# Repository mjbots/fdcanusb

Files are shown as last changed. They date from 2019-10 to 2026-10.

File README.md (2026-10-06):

# mjcanfd-usb-1x / fdcanusb

The mjcanfd-usb-1x and fdcanusb provide access to a CAN-FD bus using a
USB 2.0 full speed connection.  They present two possible interfaces:

1. A `gs_usb` interface compatible with the Linux kernel `gs_usb` socketcan driver
2. serial-like interface over the USB port using the CDC ACM class, i.e. a virtual COM port.

The designs and firmware are licensed under the Apache 2.0 License.

 * 

Pre-assembled hardware can be purchased at https://mjbots.com/products/fdcanusb

## Usage with moteus tools and libraries

To use a device with moteus tools or libraries, first install the
relevant udev rule following the instructions in the top of the file:

* [70-fdcanusb.rules](70-fdcanusb.rules)

Second, just use the application.  moteus utilities like
`moteus_tool`, `tview`, and the python and C++ libraries will
automatically discover any connected devices and use the CDC protocol.

## USB CDC Protocol

Each command or response is a single newline terminated line, composed
of 7-bit ASCII encoded characters.  Every command sent from the client
to the device has a response which consists of an optional command
specific response followed by a final line consisting solely of `OK` or
`ERR <details>`.

### States

The device can be in one of two states.

1. *Bus Off*: This is the initial state of the device.  In this state,
no frames may be sent or received, but the device may be configured.

2. *Bus On*: In this state frames may be sent and received, but
configuration is locked out.

## Commands

Sample commands are prefixed with `>` to show the data sent from the
client to the device and `<` to show the values sent from the device
to the client.  Those characters are for illustrative purposes only,
and are not present in actual communications.

### *conf*

The "conf" command is used to read and set configuration values.  It
has several subcommands.

#### *conf enumerate*

This emits all current configuration values one after another.

#### *conf get*

This queries the value of one specific configuration item.

```
>conf get sample.value
<31235
<OK
```

#### *conf set*

This sets the value of one specific configuration itme.

```
>conf set sample.value 1234
<OK
```

#### *conf load*

This loads all persistent configuration from the persistent storage.

```
>conf load
<OK
```

#### *conf write*

This stores all configuration values to persistent storage.  They will
then be the default when the device is powered on the in the future.

```
>conf write
<OK
```

#### *conf default*

Reset all configuration values to their "default" state.

```
>conf default
<OK
```

### can

#### *can on*

Enter the "Bus On" state.  All configurable values are validated and
put into place.  This results in an error if the device is already in
the "Bus On" state.

#### *can off*

Enter the "Bus Off" state.  Transmission and reception of CAN messages
is halted, and configurable values may be changed.

#### *can std*

Send a standard CAN frame.  The following format is used.

`can std <HEXID> <HEXDATA> <options>`

`options` may be zero or more of the following optionally separated by
spaces.

1. *B/b* require/disable bitrate switching
2. *F/f* require/disable FDCAN format
3. *R/r* require/disable remote frame

#### *can ext*

Send an extended CAN frame.  The following format is used.

`can ext <HEXID> <HEXDATA> <options>`

The allowable options are the same as for `can std`.

#### *can send*

Just like `std` or `ext`, but auto-detect the ID type.

#### *can status*

Report the current mode and status of various flags.

```
>can status
<mode:BUSON
<OK
```

### Receiving CAN Frames

When in the "Bus On" state, the device may spontaneously emit the
following lines upon receipt of valid CAN frames or other errors.

#### *rcv*

A CAN frame has been received.

```
<rcv <HEXID> <HEXDATA> <flags>
```

`flags` may be zero of more of the following separated by spaces:

1. *E/e* frame was received with extended/classic ID
1. *B/b* frame was received with/without bitrate switching
2. *F/f* frame was received in fdcan/classic mode
3. *R/r* frame was remote/data frame
4. tNNNNN timestamp of receipt measured in microseconds
5. fNN integer ID of which filter matched this frame

### Configurable Values

The following items may be configured.

* *can.bitrate* - The bitrate used for the CAN frame (or header only
  if bitrate switching is used.
* *can.fd_bitrate* - The bitrate used for the data and CRC field when
  bitrate switching is used.
* *can.sample_point* - The sample point for the nominal part of the
  CAN frame.  moteus requires 0.666, some other systems default to
  0.75, 0.8, or 0.87.
* *can.fd_sample_sample* - The sample point for the data (BRS) part of
  the CAN frame.  moteus requires 0.666, other systems may require
  alternate settings.
* *can.automatic_retransmission* - When true/non-zero, frames will be
  retried until acknowledged.
* *can.fdcan_frame* - By default, send frames in FDCAN mode
* *can.bitrate_switch* - By default, switch to the `can.fd_bitrate`
  for the data and CRC fields.
* *can.restricted_mode* - Only transmit acknowledgements.
* *can.bus_monitor* - Transmit nothing.
* *can.termination* - Enable the onboard terminator
* *can.autostart* - Enter BusOn immediately at power-on
* *can.autorecover* - Automatically recover from bus off events

* *can.global.std_action*
* *can.global.ext_action*
* *can.global.remote_std_action*
* *can.global.remote_ext_action*
  * 0/1 - accept
  * 2 - reject

* *can.filter.N.id1* - first ID
* *can.filter.N.id2* - second ID or bitmask
* *can.filter.N.mode*
  * 0 - range
  * 1 - exact match
  * 2 - bitmask
* *can.filter.N.type*
  * 0 - standard
  * 1 - extended
* *can.filter.N.action*
  * 0 - disable
  * 1 - accept
  * 2 - reject

## gs_usb interface

To use the device with a socketcan driver on Linux, the normal socketcan utilities can be used.  For instance, to bring up an interface compatible with moteus (not usually required because moteus tools and libraries will by default use the CDC interface), you would do:

```bash
ip link set can0 up type can \
  bitrate 1000000 dbitrate 5000000 \
  sjw 10 dsjw 5 \
  sample-point 0.666 dsample-point 0.666 \
  fd on
```

Then, all messages received can be displayed with:

```bash
candump can0
```

## Building firmware

To build the firmware on an Ubuntu 22.04 or newer system.

```
sudo apt install curl openocd
./tools/bazel build //...
```

To flash:

```
./flash.py
```

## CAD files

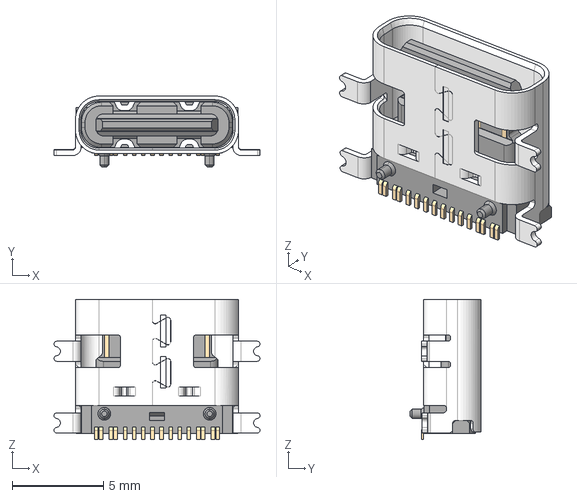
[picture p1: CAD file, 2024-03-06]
hw/3d/usb4110-gf-a.stp
11.3 x 3.89 x 7.70 mm

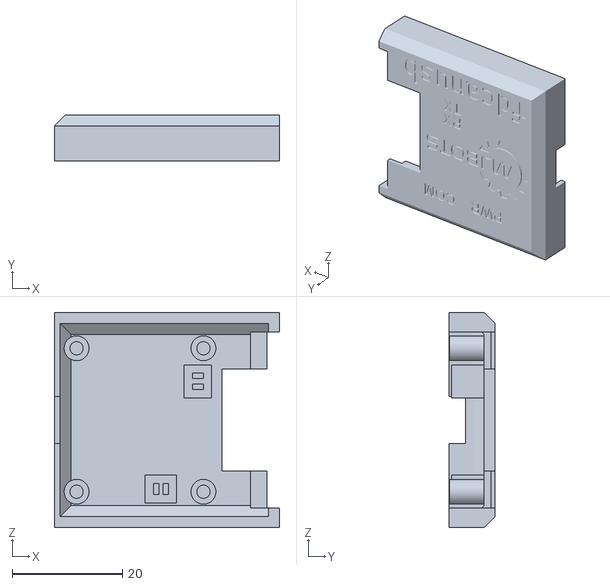
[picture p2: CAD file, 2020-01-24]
hw/enclosure/fdcanusb_20200122/fdcanusb_enclosure_top.stl
40.8 x 8.40 x 39.0

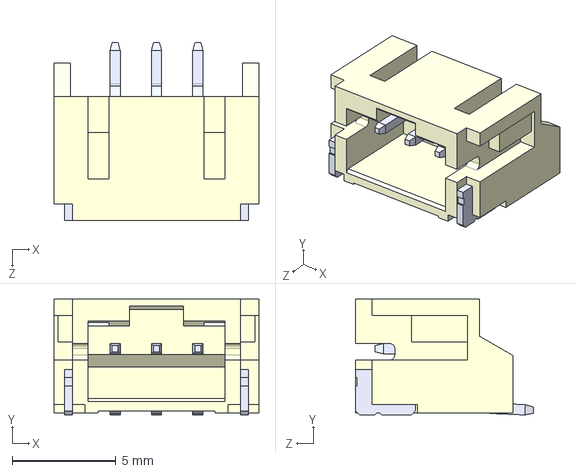
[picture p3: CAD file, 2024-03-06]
hw/3d/S3B-PH-SM4-TB_LF__SN_.step
9.90 x 5.60 x 8.60 mm

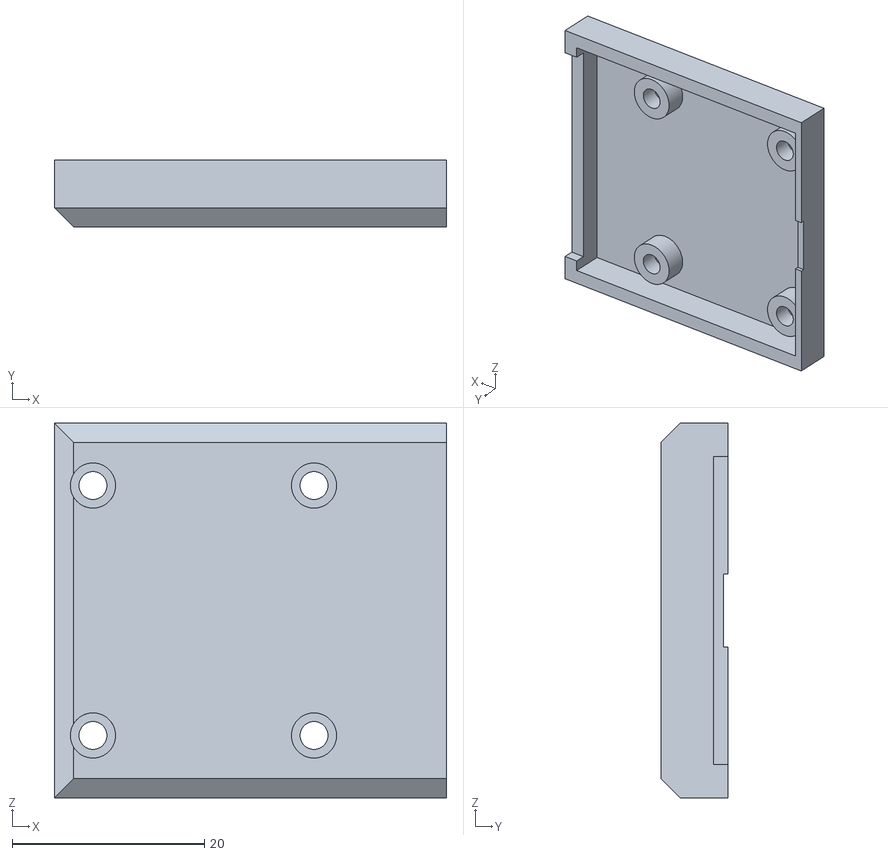
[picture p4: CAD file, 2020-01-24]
hw/enclosure/fdcanusb_20200122/fdcanusb_enclosure_bottom.stl
40.8 x 7.00 x 39.0

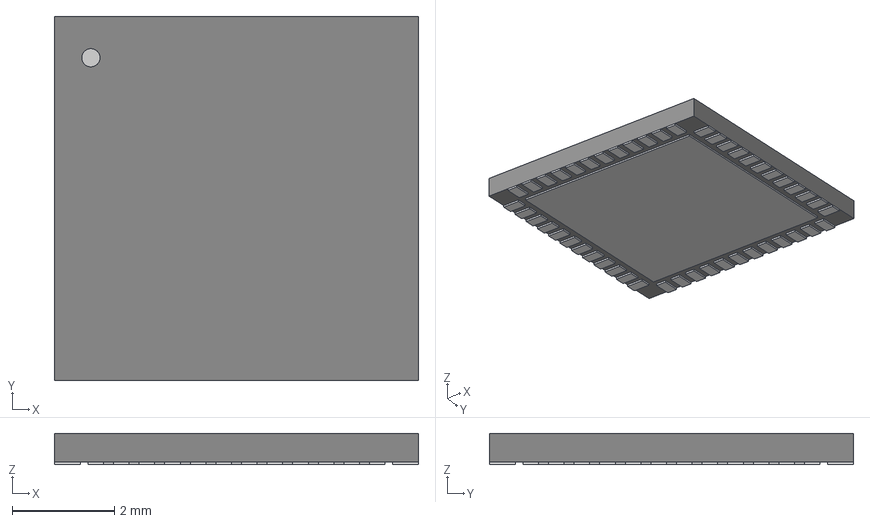
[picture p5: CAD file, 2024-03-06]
hw/3d/UFQFPN-48_7X7X0P55MM.step
7.11 x 7.11 x 0.612 mm

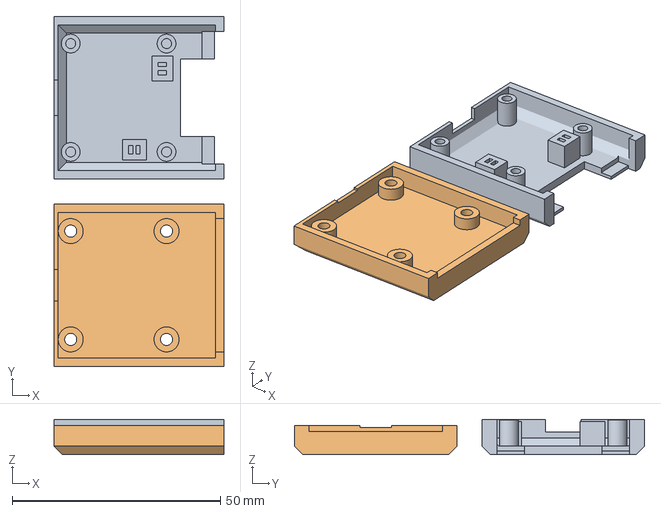
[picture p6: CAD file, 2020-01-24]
hw/enclosure/fdcanusb_20200122/fdcanusb_enclosure.3mf
40.8 x 84.0 x 8.40 mm
fdcanusb_enclosure_top.stl
fdcanusb_enclosure_bottom.stl

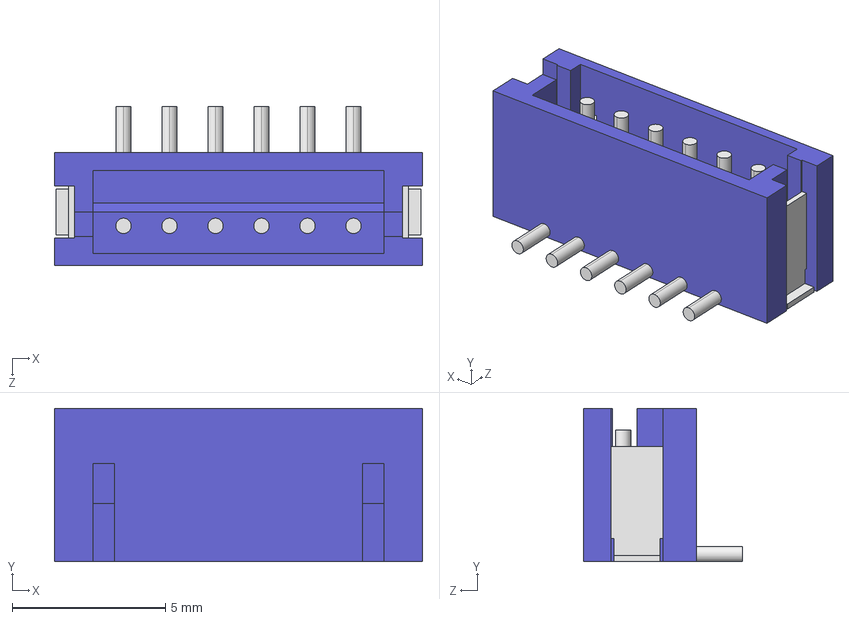
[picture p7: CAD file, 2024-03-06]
hw/3d/B6B-ZR-SM4-TF.STEP
12.0 x 5.00 x 5.20 mm

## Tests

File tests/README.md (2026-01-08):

# fdcanusb Hardware-in-the-Loop Test Suite

Some tests can be performed using a physical test fixture.

## Hardware Overview

The test fixture consists of:

* A Legacy CDC-based fdcanusb: serial B79E5874
* The Device Under Test (DUT): serial 79678ECE
* A debug UART: /dev/serial/by-id/usb-FTDI_UMFT230XB_FT6VJM97-if00-port0`

The two fdcanusb devices are connected onto a common CAN bus, and the
debug UART is connected to the TX LED of the DUT under test.

## Prerequisites

```bash
sudo apt install can-utils
```

## Usage

Several commands either need to be configured for passwordless `sudo`,
or the tests must be run as root.

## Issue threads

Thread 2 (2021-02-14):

CAN Socket support?

vibnwis, 2021-02-14:
Does it support CAN Socket?

jpieper, 2021-02-14:
The daemon found here https://github.com/mjbots/fdcanusb/blob/master/sw/fdcanusb_daemon.cc can be used to provide a socketcan interface from the fdcanusb.

vibnwis, 2021-02-14:
Many thanks for the response. However, having searched high and low, yet not seeing the hardware for your code.  What or where is the hardware?

jpieper, 2021-02-14:
https://github.com/mjbots/fdcanusb/tree/master/hw

jpieper, 2021-02-14:
When they are in stock, you can also buy them at https://mjbots.com/products/fdcanusb

vibnwis, 2021-02-14:
The description of "serial-like" is confusing, despite me a embedded
engineer and familiar with CAN-bus not so sure it is a CAN-bus device or
Serial-like CAN-bus, please elaborate?

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

jpieper, 2021-02-14:
When inserted into a USB port, it implements the USB CDC interface.  That means it looks like a virtual COM port to Window or Linux.

When you use a terminal emulator like hyperterminal or minicom, it allows you to send commands which cause CAN-FD frames to be emitted out the other side.  CAN-FD frames that are successfully received, are reported as responses on that same USB CDC interface.

vibnwis, 2021-02-14:
Thank you for the explanation. I need a USB-FDCAN adapter. Your product
does not suit my needs. Thank you

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

jpieper, 2021-02-14:
No worries.  Although, a USB CAN-FD adapter is exactly what this is.  I'm not sure what else you would expect from such an adapter.

vibnwis, 2021-02-14:
Simply, USB<->CANFD, so that I can have an FDCAN device on my PC through
USB.

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

jpieper, 2021-02-14:
That is exactly what this device lets you do.

Every USB to CAN-FD adapter has a unique protocol on the PC side.  The fdcanusb's is documented in the README, and additionally there is the daemon linked above that lets it present as a linux socketcan device.

vibnwis, 2021-02-14:
I re-visited your explanation, and realize that the serial-like is an emulation. Without emulation, it is a USB-FDCAN device. I need a device for my research studies. Hence, do not have much time for trouble-shooting. Is the product as CAN Socket promising or working. I can compile the Linux driver, but just wanting to know it is not stable, not a beta release, is it?

jpieper, 2021-02-14:
It is plenty stable for mjbots' needs.  However, you may decide you'd rather get something like the PEAK USB CAN-FD adapter, which while significantly more expensive, is provided by a company with a longer history.

https://www.peak-system.com/PCAN-USB-FD.365.0.html?&L=1

vibnwis, 2021-02-14:
However, the website says it is out of stock and sold out?

jpieper, 2021-02-14:
Yes, as the website says, the ETA of new stock is approximately 1 week.

vibnwis, 2021-02-14:
How does it take an order?

jpieper, 2021-02-14:
If you are asking how to place an order at mjbots.com, you can wait until it is in stock, then pay with a credit card or google pay using the automated online checkout.

vibnwis, 2021-02-14:
Got it! I was thinking if I can place an order now, and pay when it is in
stock. All good. Thanks

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

jpieper, 2021-02-14:
Great!  I'll close this issue out for now then.  If you have more questions, don't hesitate to mail info@mjbots.com or joint the mjbots discord: https://discord.gg/W4hUpBb

vibnwis, 2021-02-25:
Hi there,
The FDCAN USB adapter is available now. However, it does not ship to New Zealand. Can you help, please?

jpieper, 2021-02-25:
Shipping to New Zealand should work.  Can you mail info@mjbots.com with a screenshot of any errors you are seeing?

vibnwis, 2021-02-25:
Sent

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

Closed 2021-02-14.

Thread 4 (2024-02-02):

Configuration is not saved well

remixoff, 2024-02-02:
```
conf set can.restricted_mode  0
OK
conf write
OK
conf get can.restricted_mode
ERR error reading
```

jpieper, 2024-02-02:
Likely you used backspace or other non-printable characters.  While human readable, the protocol isn't necessarily human friendly.

```
conf enumerate
```

Will also display all configuration.  Can you try again, perhaps pasting to avoid having to backspace?

jpieper, 2024-04-12:
Closing this as there as been no response.

Closed 2024-04-12.

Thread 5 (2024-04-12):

build error

AoyunTech, 2024-04-12:
Hi Josh,
 Would you know how to fix this build errs?

Thanks

~/github/mjbots/fdcanusb$ ./tools/bazel build //fw:fdcanusb.bin
Downloading bazel 5.4.1 from https://github.com/bazelbuild/bazel/releases/download/5.4.1/bazel-5.4.1-linux-x86_64
  % Total    % Received % Xferd  Average Speed   Time    Time     Time  Current
                                 Dload  Upload   Total   Spent    Left  Speed
  0     0    0     0    0     0      0      0 --:--:--  0:00:32 --:--:--     0
100 49.4M  100 49.4M    0     0  45333      0  0:19:03  0:19:03 --:--:-- 1738k
Traceback (most recent call last):
  File "./tools/bazel", line 108, in <module>
    main()
  File "./tools/bazel", line 101, in main
    download_bazel(bazel_bin_loc)
  File "./tools/bazel", line 88, in download_bazel
    raise RuntimeError(
RuntimeError: bazel sha256 does not match, expected e3b0c44298fc1c149afbf4c8996fb92427ae41e4649b934ca495991b7852b855 got 5d90515f84b5ee1fd6ec22ee9e83103e77ed1a907ee5eec198fef3a5b45abf13

jpieper, 2024-04-12:
You likely have a proxy or something that is modifying the contents of the file that it is downloading: https://github.com/bazelbuild/bazel/releases/download/5.4.1/bazel-5.4.1-linux-x86_64

I just downloaded it here again and got the expected hash of 5d90515f84b5ee1fd6ec22ee9e83103e77ed1a907ee5eec198fef3a5b45abf13 which is what is present in https://github.com/mjbots/fdcanusb/blob/7b0a188b39cb8ea94958e9601762a55b619bf2a0/WORKSPACE#L20

AoyunTech, 2024-04-13:
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

Hi Josh,
It's my mistakes.

Thanks for your reply!
Thanks

But i missed another issue when retry building again.
LOG as
1:~/github/mjbots/fdcanusb$ ./tools/bazel build //fw:fdcanusb.bin
Traceback (most recent call last):
  File "./tools/bazel", line 107, in <module>
    main()
  File "./tools/bazel", line 102, in main
    os.execv(bazel_bin_loc, ['bazel', ] + sys.argv[1:])
OSError: [Errno 8] Exec format error

Hope your suggestions please.

jpieper, 2024-04-13:
The build process is only supported on a x64 Linux system.  I'm guessing you have a different architecture or OS.

Closed 2024-10-16.

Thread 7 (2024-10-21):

Could not detect fdcanusb

bybayin, 2024-10-21:
Hello, I have a problem and I was wondering if you could help me. When I was trying to connect to the FDCANUSB, I got an unexpected message in the console that says "Could not detect FDCANUSB." How can I resolve this issue?
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

jpieper, 2024-10-21:
Do you have a fdcanusb connected to your computer?  Is the red PWR light illuminated on the fdcanusb?

bybayin, 2024-10-21:
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

This is the source code I compiled for fdcanUSB and burned it onto my custom PCB board. The burning program was successful, but the PWR light did not turn on after powering on. The computer USB recognized this device as DFU in FS Mode

jpieper, 2024-10-21:
mjbots does not provide support for custom built boards.  If you have further issues, you should ask in the mjbots Discord in the #ibuiltit channel: https://discord.gg/W4hUpBb

That said, it sounds like you have not set the option bytes.  There is a script in the moteus repo: https://github.com/mjbots/moteus/blob/main/fw/program_option_bytes.sh

Closed 2024-10-21.

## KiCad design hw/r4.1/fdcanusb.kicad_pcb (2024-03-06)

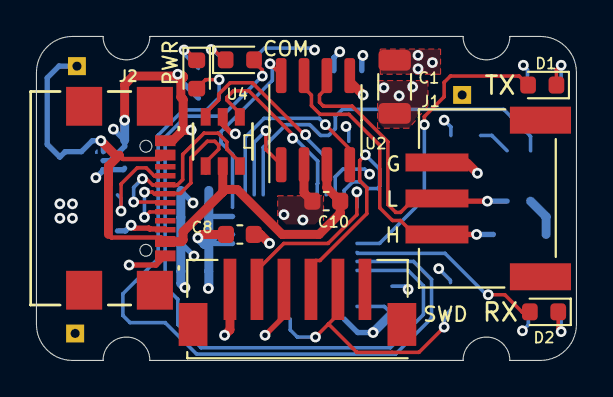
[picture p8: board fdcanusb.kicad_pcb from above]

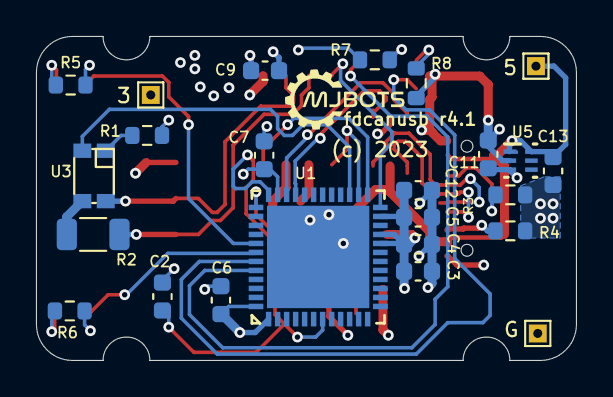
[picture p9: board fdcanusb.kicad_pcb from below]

Board: 4 copper layers, 30.0 x 18.0 mm, 36 parts (24 on the bottom side), 28 nets.

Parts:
C1: 10uF; C_1206_3216Metric
C2, C4, C6, C7, C8, C9, C10, C12: 0.1uF; C_0603_1608Metric
C3: 4.7uF; C_0603_1608Metric
C5, C11, C13: 1uF; C_0603_1608Metric
D1, D3: GREEN; LED_0603_1608Metric
D2, D4: RED; LED_0603_1608Metric
J1: Conn_01x03; JST_S3B-PH-SM4-TB(LF)(SN)
J2: USB4110-GF-A; USB4110-GF-A_GCT
J3, J4, J5: Conn_01x01; TestPoint_THTPad_1.0x1.0mm_Drill0.5mm
R1: 330; R_0603_1608Metric
R2: 110; R_1206_3216Metric
R3, R4: 5.1k; R_0603_1608Metric
R5, R6, R7, R8: 220; R_0603_1608Metric
SWD1: B6B-ZR-SM4-TF(LF)(SN); B6B-ZR-SM4-TFLFSN
U1: STM32G474CEU6; UFQFPN-48_7X7X0P55MM
U2: TCAN1057AEVDRQ1; SOIC-8_3.9x4.9mm_P1.27mm
U3: TLP3317
U4: USBLC6-2SC6; SOT23-6L_STM
U5: TLV70233DSER; DSE0006A

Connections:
+3V: C1.1, C3.1, C4.1, C5.1, C6.1, C7.1, C8.1, C9.1, C11.1, C12.1, J4.1, R1.1, SWD1.6, U1.1 (VBAT), U1.20 (VREF+), U1.21 (VDDA), U1.23 (VDD), U1.35 (VDD), U1.48 (VDD), U2.5 (VIO), U5.3 (OUT)
+5V: C10.1, C13.1, J2.A4-B9 (VBUS), J2.A9-B4 (VBUS), J5.1, U2.3 (VCC), U4.5, U5.1 (IN), U5.6 (EN)
/CAN/CAN_N: J1.2, U2.6 (CANL), U3.4
/CAN/CAN_P: J1.1, R2.2, U2.7 (CANH)
/CAN/CAN_RX: U1.25 (PB12), U2.4 (RXD)
/CAN/CAN_STB: U1.24 (PB11), U2.8 (STB)
/CAN/CAN_TERM: U1.27 (PB14), U3.2
/CAN/CAN_TX: U1.26 (PB13), U2.1 (TXD)
/LED Debug/LED_CAN_RX: D2.2 (A), U1.42 (PB4)
/LED Debug/LED_CAN_TX: D1.2 (A), U1.41 (PB3)
/LED Debug/LED_COM: D3.2 (A), U1.44 (PB6)
/LED Debug/LED_PWR: D4.2 (A), U1.43 (PB5)
/Power Input/USB_F_N: U1.33 (PA11), U4.1
/Power Input/USB_F_P: U1.34 (PA12), U4.3
/Power Input/USB_N: J2.A7 (DN1), J2.B7 (DN2), U4.6
/Power Input/USB_P: J2.A6 (DP1), J2.B6 (DP2), U4.4
/stm32g4/NRST: C2.1, SWD1.2, U1.7 (PG10-NRST)
/stm32g4/SWCLK: SWD1.5, U1.37 (PA14)
/stm32g4/SWDIO: SWD1.3, U1.36 (PA13)
GND: C1.2, C2.2, C3.2, C4.2, C5.2, C6.2, C7.2, C8.2, C9.2, C10.2, C11.2, C12.2, C13.2, J1.3, J2.A1-B12 (GND), J2.A12-B1 (GND), J3.1, R3.2, R4.2, R5.2, R6.2, R7.2, R8.2, SWD1.4, U1.49 (EPAD), U2.2 (GND), U4.2, U5.2 (GND)
unnamed: D1.1 (K), R5.1
unnamed: D2.1 (K), R6.1
unnamed: D3.1 (K), R7.1
unnamed: D4.1 (K), R8.1
unnamed: J2.A5 (CC1), R3.1
unnamed: J2.B5 (CC2), R4.1
unnamed: R1.2, U3.1
unnamed: R2.1, U3.3

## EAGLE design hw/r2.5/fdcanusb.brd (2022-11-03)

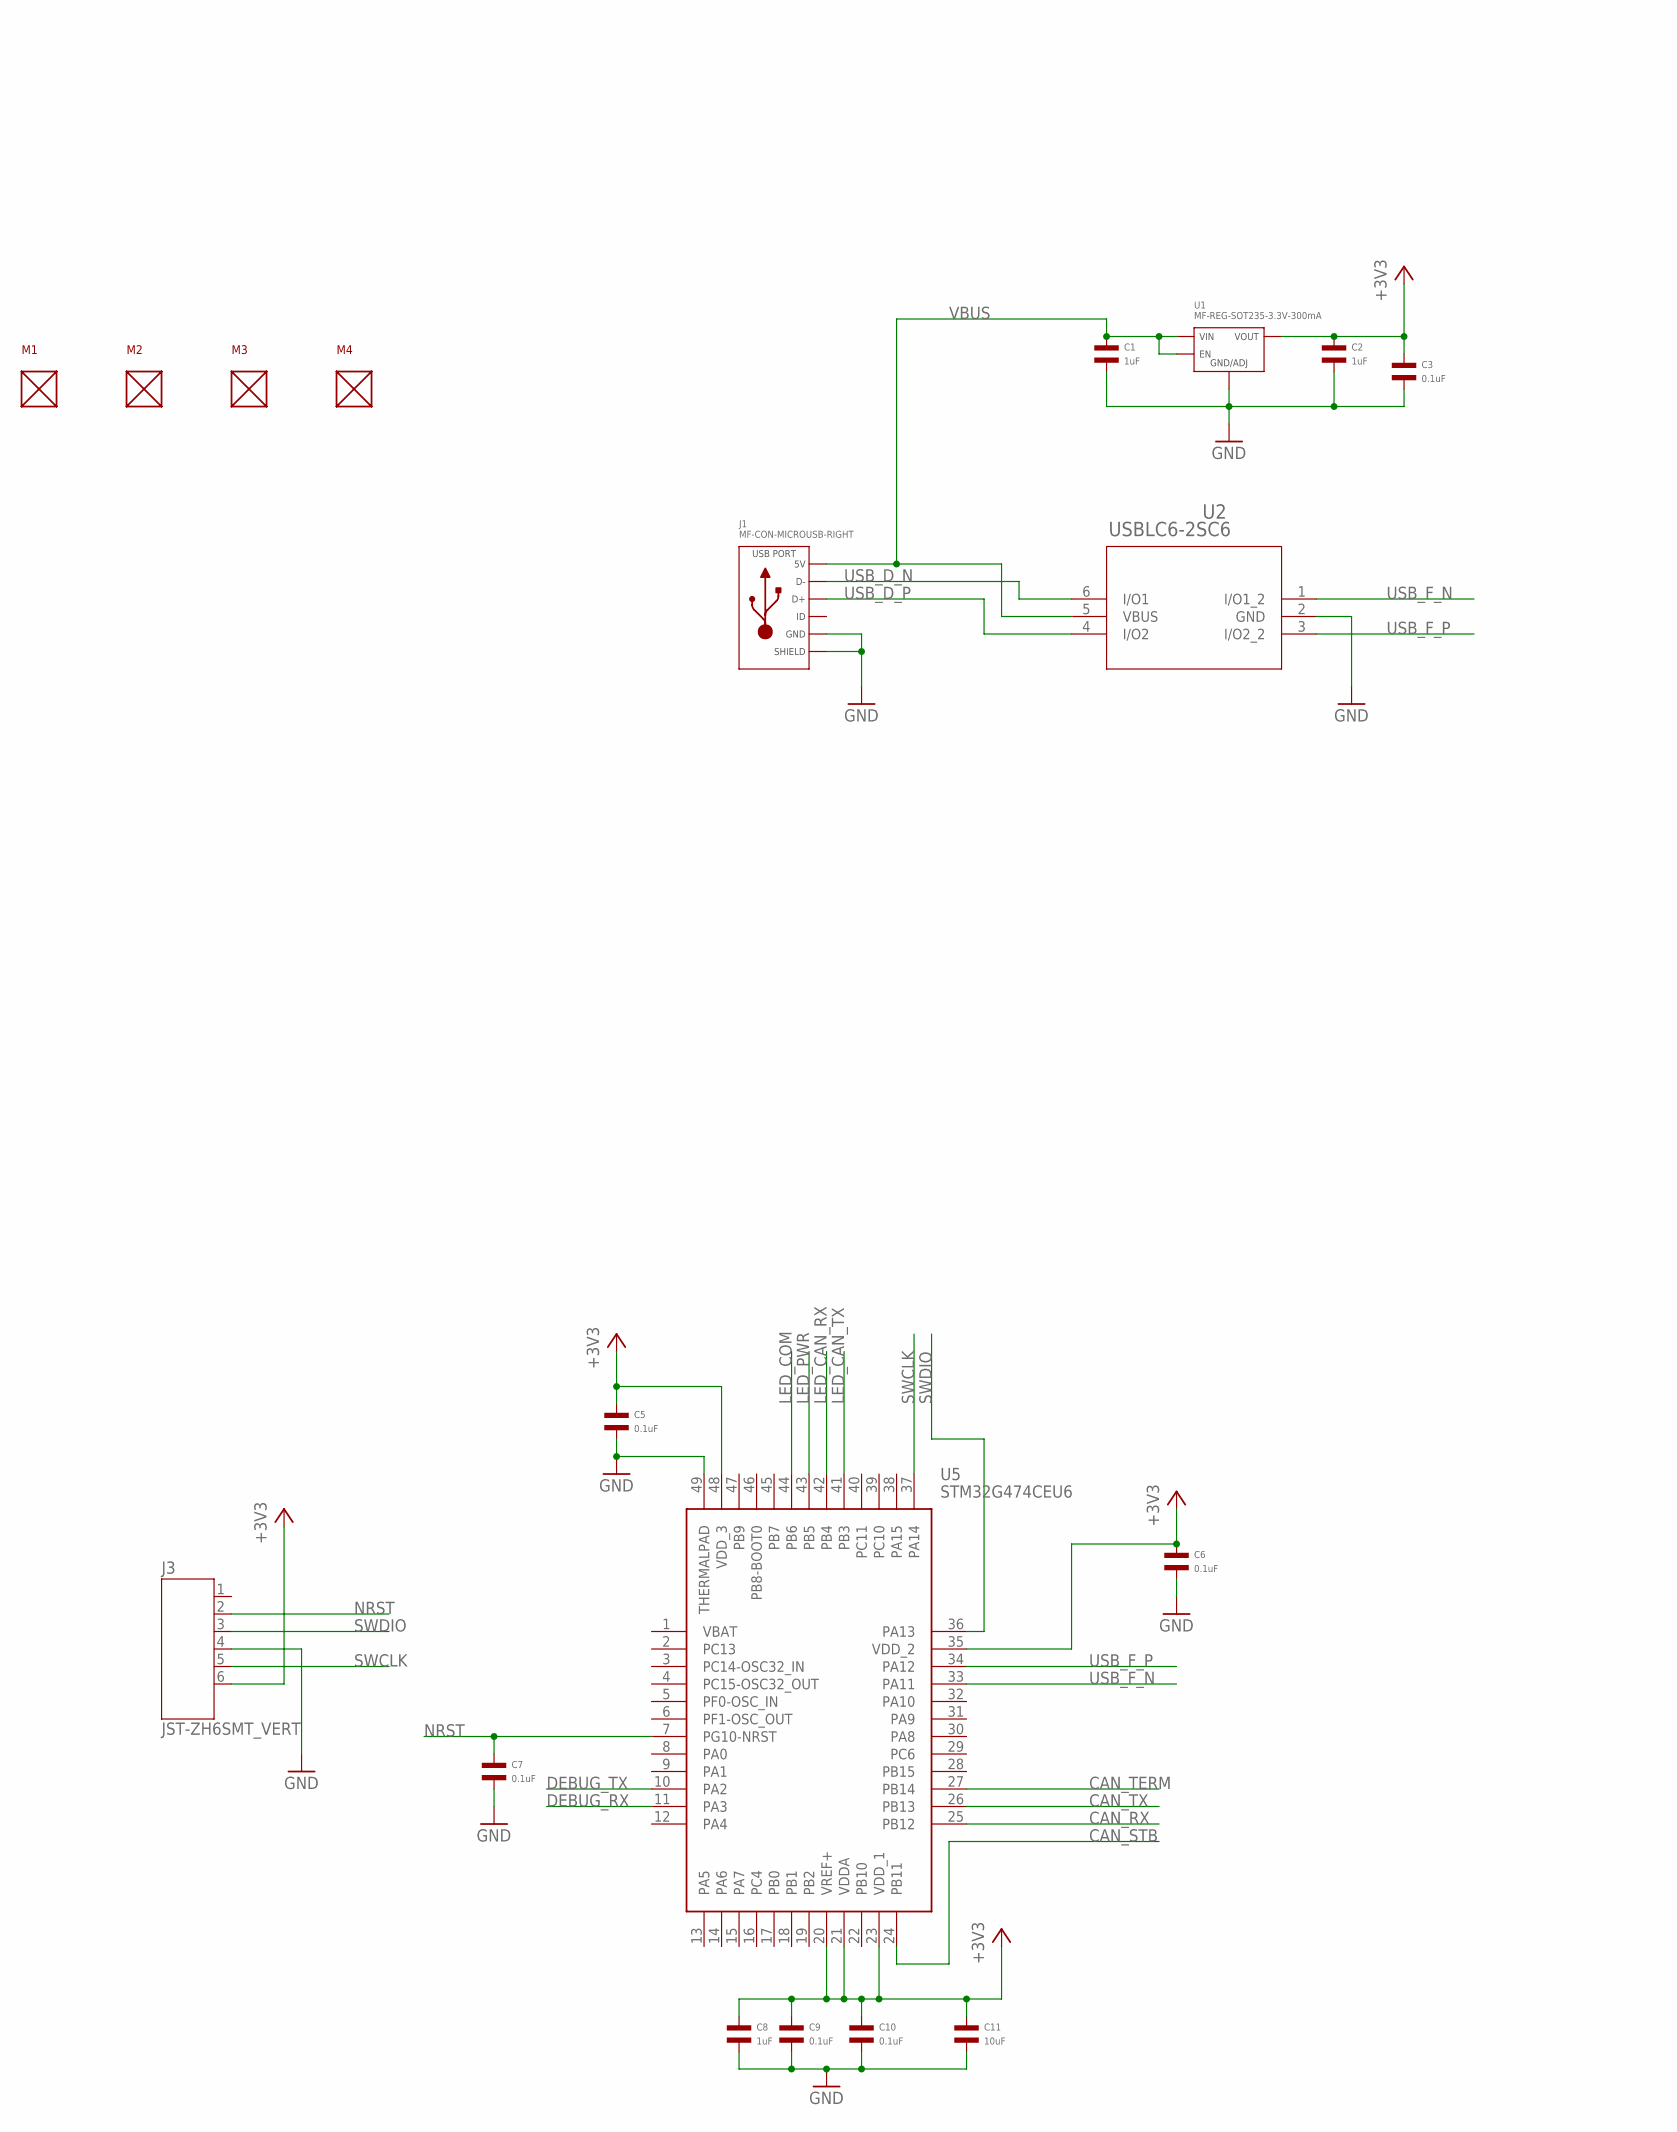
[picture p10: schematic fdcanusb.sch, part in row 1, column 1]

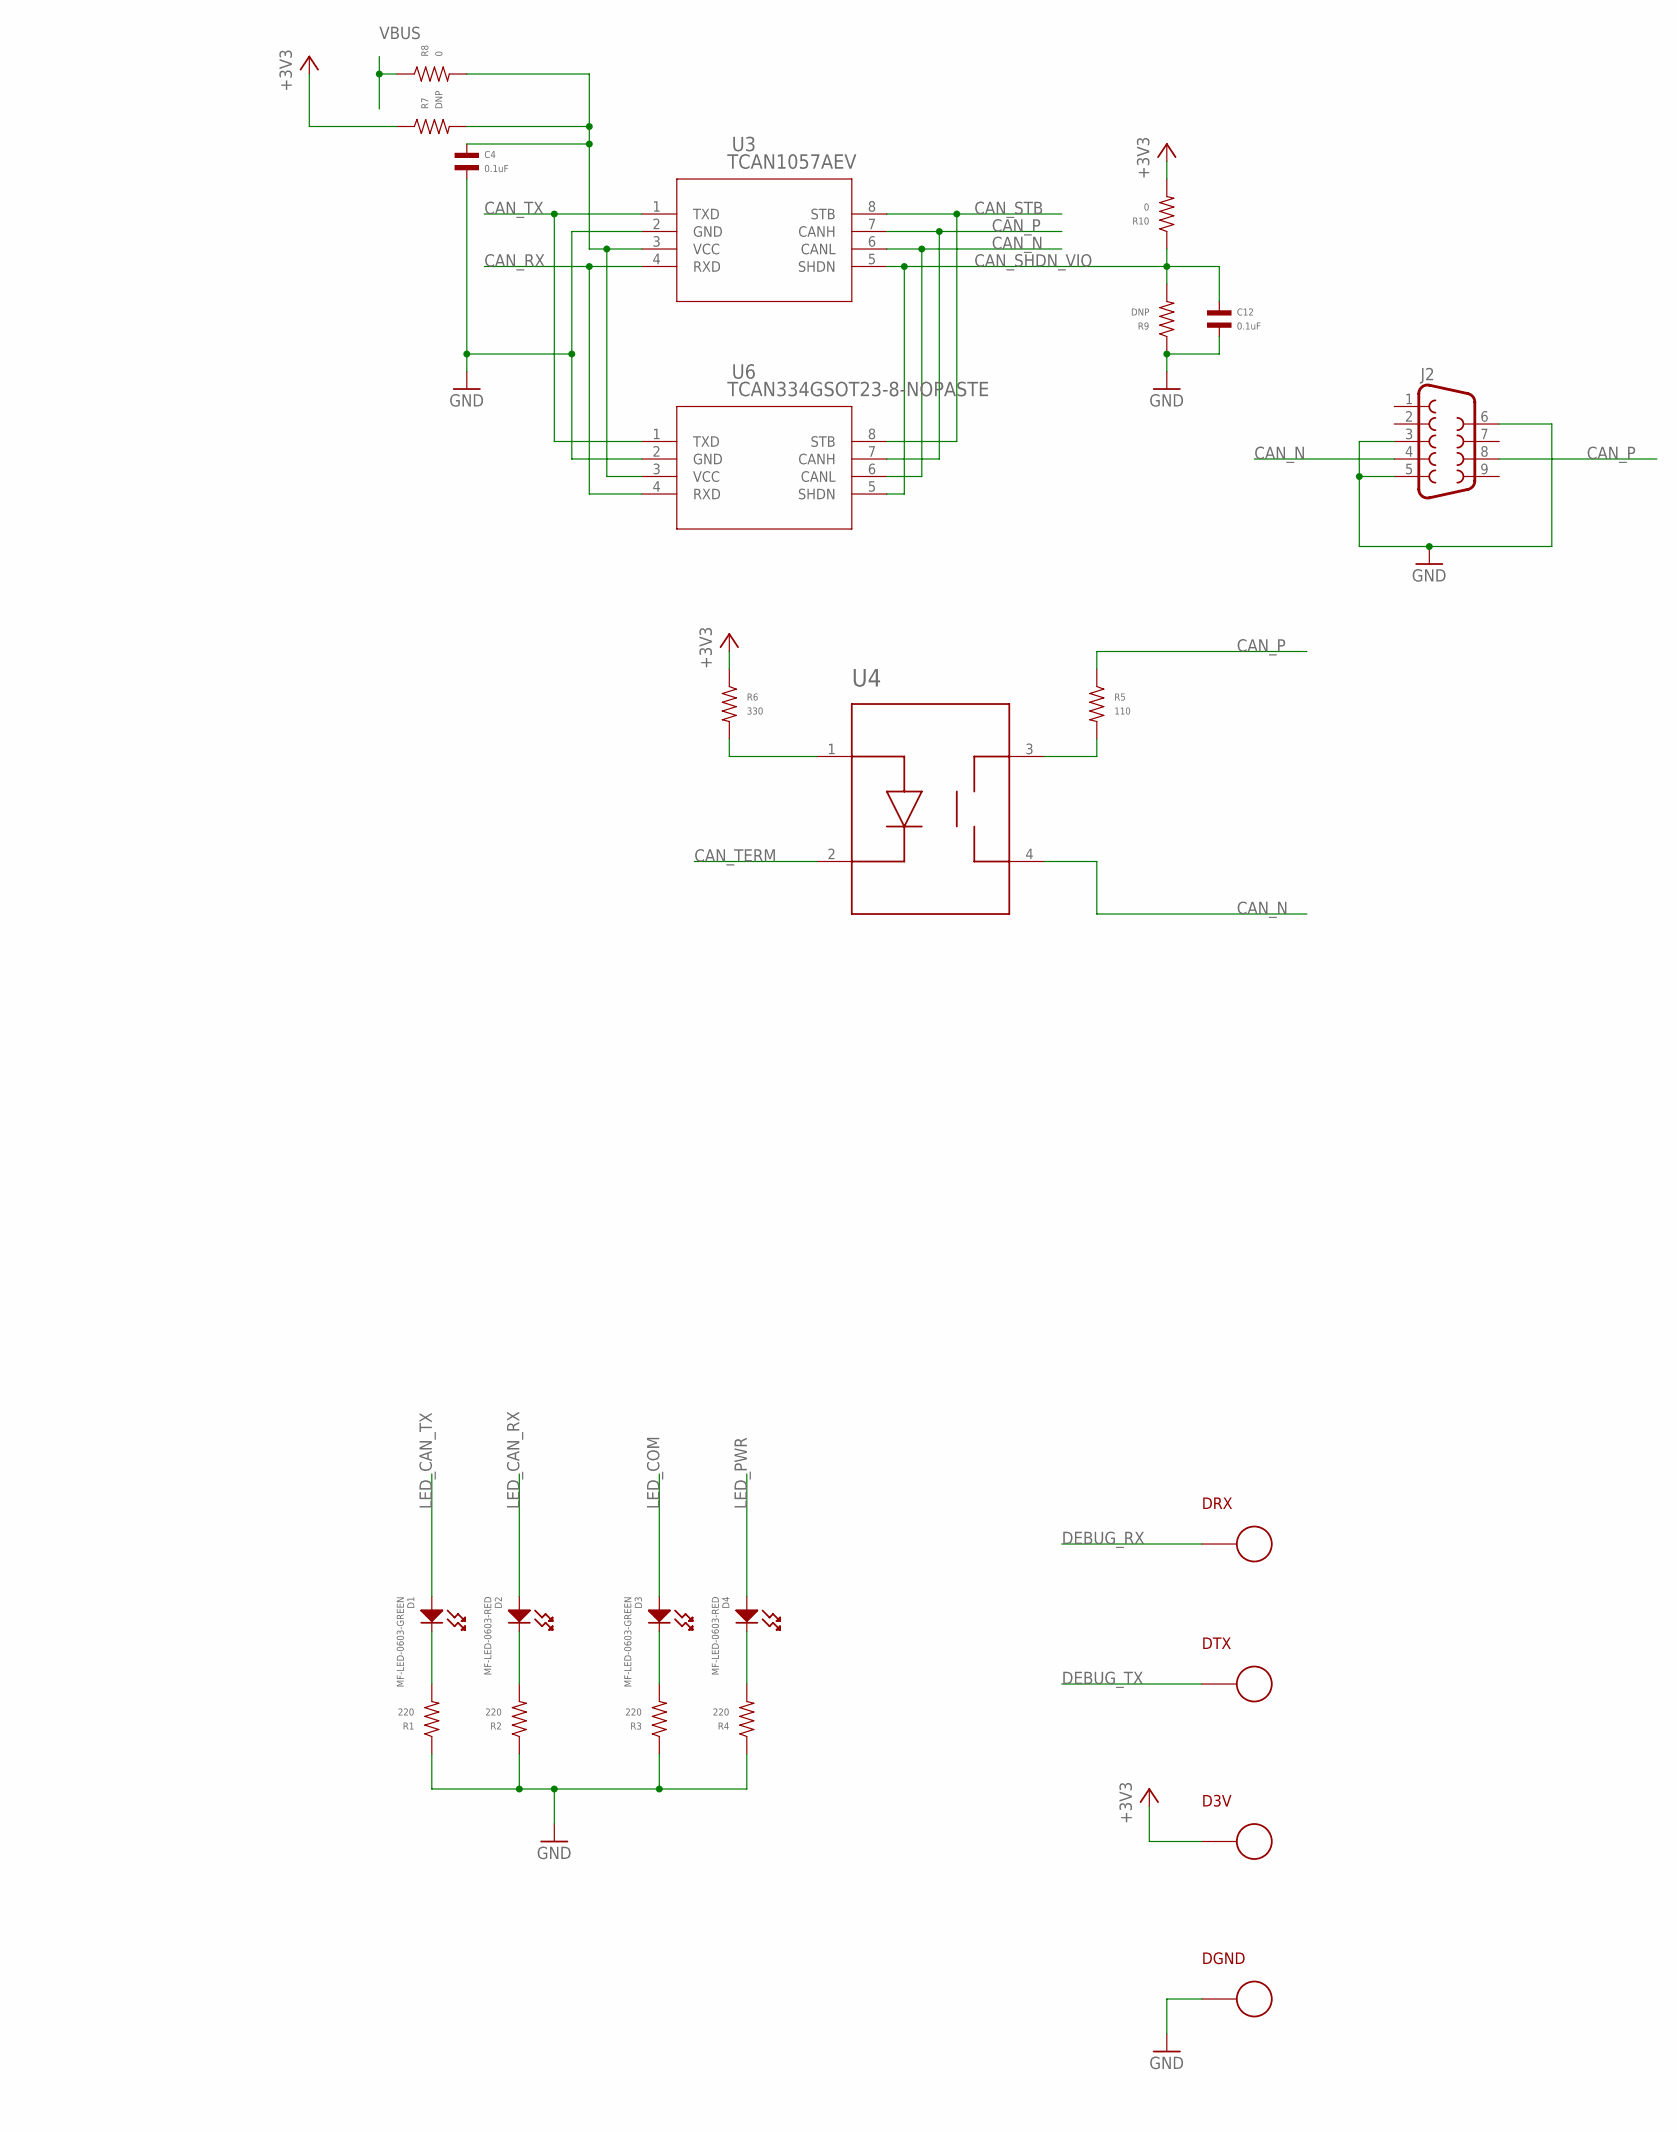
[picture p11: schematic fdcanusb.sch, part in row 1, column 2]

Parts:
C1, C2, C8: 1uF; C0603; MPN MF-CAP-0603-1uF
C3, C4, C5, C6, C7, C9, C10, C12: 0.1uF; C0603; MPN MF-CAP-0603-0.1uF
C11: 10uF; C1206; MPN MF-CAP-1206-10uF
D1, D3: MF-LED-0603-GREEN; LED0603
D2, D4: MF-LED-0603-RED; LED0603
D3V: PAD24AWG_PAD; 24AWG_PAD
DGND: PAD24AWG_PAD; 24AWG_PAD
DRX: PAD24AWG_PAD; 24AWG_PAD
DTX: PAD24AWG_PAD; 24AWG_PAD
J1: MF-CON-MICROUSB-RIGHT; MICROUSB-RIGHT
J2: F09; DB09_PLATED
J3: JST-ZH6SMT_VERT; JST_B6B-ZR-SM4-TF(LF)(SN); MPN B6B-ZR-SM4-TF(LF)(SN)
M1, M2, M3, M4: MOUNT; M2.5MOUNT
R1, R2, R3, R4: 220; R0603; MPN MF-RES-0603-220
R5: 110; R0603; MPN RC0603FR-07110RL
R6: 330; R0603; MPN MF-RES-0603-330
R7, R9: DNP; R0603
R8, R10: 0; R0603; MPN MF-RES-0603-0
U1: MF-REG-SOT235-3.3V-300mA; SOT-23-5
U2: USBLC6-2SC6; SOT23-6L; MPN USBLC6-2SC6
U3: TCAN1057AEV; SOIC8; MPN TCAN1057AEVDRQ1
U4: TLP3317; MPN TLP3317
U5: STM32G474CEU6; QFN50P700X700X60-49N; MPN STM32G474CEU6
U6: TCAN334GSOT23-8-NOPASTE; SOT23-8-NOPASTE; MPN TCAN334GDCNT

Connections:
+3V3: C2.P$1, C3.P$1, C5.P$1, C6.P$1, C8.P$1, C9.P$1, C10.P$1, C11.P$1, D3V.P$1, J3.6, R6.P$1, R7.P$1, R10.P$2, U1.P$5 (VOUT), U5.20 (VREF+), U5.21 (VDDA), U5.23 (VDD_1), U5.35 (VDD_2), U5.48 (VDD_3)
CAN_N: J2.4, U3.6 (CANL), U4.4 (SW2), U6.6 (CANL)
CAN_P: J2.8, R5.P$1, U3.7 (CANH), U6.7 (CANH)
CAN_RX: U3.4 (RXD), U5.25 (PB12), U6.4 (RXD)
CAN_SHDN_VIO: C12.P$1, R9.P$2, R10.P$1, U3.5 (SHDN), U6.5 (SHDN)
CAN_STB: U3.8 (STB), U5.24 (PB11), U6.8 (STB)
CAN_TERM: U4.2 (CATHODE), U5.27 (PB14)
CAN_TX: U3.1 (TXD), U5.26 (PB13), U6.1 (TXD)
DEBUG_RX: DRX.P$1, U5.11 (PA3)
DEBUG_TX: DTX.P$1, U5.10 (PA2)
GND: C1.P$2, C2.P$2, C3.P$2, C4.P$2, C5.P$2, C6.P$2, C7.P$2, C8.P$2, C9.P$2, C10.P$2, C11.P$2, C12.P$2, DGND.P$1, J1.5 (GND), J1.S1 (SLD), J1.S2 (SLD), J1.S3 (SLD), J1.S4 (SLD), J1.S5 (SLD), J1.S6 (SLD), J2.3, J2.5, J2.6, J3.4, R1.P$1, R2.P$1, R3.P$1, R4.P$1, R9.P$1, U1.P$2 (GND/ADJ), U2.2 (GND), U3.2 (GND), U5.49 (THERMALPAD), U6.2 (GND)
LED_CAN_RX: D2.ANODE, U5.42 (PB4)
LED_CAN_TX: D1.ANODE, U5.41 (PB3)
LED_COM: D3.ANODE, U5.44 (PB6)
LED_PWR: D4.ANODE, U5.43 (PB5)
unnamed: C4.P$1, R7.P$2, R8.P$2, U3.3 (VCC), U6.3 (VCC)
unnamed: D1.CATHODE, R1.P$2
unnamed: D2.CATHODE, R2.P$2
unnamed: D3.CATHODE, R3.P$2
unnamed: D4.CATHODE, R4.P$2
unnamed: R5.P$2, U4.3 (SW1)
unnamed: R6.P$2, U4.1 (ANODE)
NRST: C7.P$1, J3.2, U5.7 (PG10-NRST)
SWCLK: J3.5, U5.37 (PA14)
SWDIO: J3.3, U5.36 (PA13)
USB_D_N: J1.2 (D-), U2.6 (I/O1)
USB_D_P: J1.3 (D+), U2.4 (I/O2)
USB_F_N: U2.1 (I/O1_2), U5.33 (PA11)
USB_F_P: U2.3 (I/O2_2), U5.34 (PA12)
VBUS: C1.P$1, J1.1 (5V), R8.P$1, U1.P$1 (VIN), U1.P$3 (EN), U2.5 (VBUS)

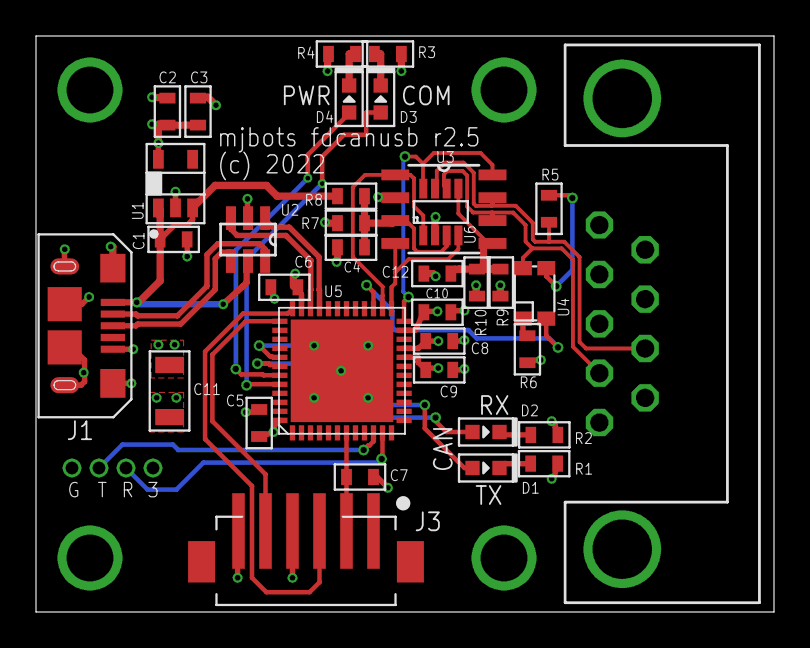
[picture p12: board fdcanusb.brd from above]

Board: 4 copper layers, 41.0 x 32.0 mm, 43 parts (0 on the bottom side), 30 nets.

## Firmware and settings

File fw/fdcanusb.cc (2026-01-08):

// Copyright 2019 Josh Pieper, jjp@pobox.com.
//
// Licensed under the Apache License, Version 2.0 (the "License");
// you may not use this file except in compliance with the License.
// You may obtain a copy of the License at
//
//     http://www.apache.org/licenses/LICENSE-2.0
//
// Unless required by applicable law or agreed to in writing, software
// distributed under the License is distributed on an "AS IS" BASIS,
// WITHOUT WARRANTIES OR CONDITIONS OF ANY KIND, either express or implied.
// See the License for the specific language governing permissions and
// limitations under the License.

#include <inttypes.h>

#include "mbed.h"
#include "PeripheralPins.h"

#include "mjlib/base/string_span.h"

#include "mjlib/micro/command_manager.h"
#include "mjlib/micro/persistent_config.h"
#include "mjlib/micro/telemetry_manager.h"

#include "fw/can_manager.h"
#include "fw/firmware_info.h"
#include "fw/git_info.h"
#include "fw/millisecond_timer.h"
#include "fw/stm32g4_async_uart.h"
#include "fw/stm32g4_flash.h"
#include "fw/stm32g4_async_usb_cdc.h"
#include "fw/stm32g4_gs_usb.h"
#include "fw/uuid.h"
#include "fw/xprintf.h"

namespace {
namespace base = mjlib::base;
namespace micro = mjlib::micro;

void SetupClock(int clock_rate_hz) {
  __HAL_RCC_SYSCFG_CLK_ENABLE();
  __HAL_RCC_PWR_CLK_ENABLE();

  RCC_ClkInitTypeDef RCC_ClkInitStruct;

  // Temporarily stop running off the PLL so we can change it.
  RCC_ClkInitStruct.ClockType      = RCC_CLOCKTYPE_SYSCLK;
  RCC_ClkInitStruct.SYSCLKSource = RCC_SYSCLKSOURCE_HSI;
  if (HAL_RCC_ClockConfig(&RCC_ClkInitStruct, FLASH_LATENCY_6) != HAL_OK) {
    mbed_die();
  }

  RCC_OscInitTypeDef RCC_OscInitStruct;

  RCC_OscInitStruct.OscillatorType = RCC_OSCILLATORTYPE_HSI|RCC_OSCILLATORTYPE_HSI48;
  RCC_OscInitStruct.HSIState = RCC_HSI_ON;
  RCC_OscInitStruct.HSICalibrationValue = RCC_HSICALIBRATION_DEFAULT;
  RCC_OscInitStruct.HSI48State = RCC_HSI48_ON;
  RCC_OscInitStruct.PLL.PLLState = RCC_PLL_ON;
  RCC_OscInitStruct.PLL.PLLSource = RCC_PLLSOURCE_HSI;
  RCC_OscInitStruct.PLL.PLLM = RCC_PLLM_DIV4;
  RCC_OscInitStruct.PLL.PLLN = (clock_rate_hz / 1000000) * 24 / 48;
  RCC_OscInitStruct.PLL.PLLP = RCC_PLLP_DIV2;
  RCC_OscInitStruct.PLL.PLLQ = RCC_PLLQ_DIV2;
  RCC_OscInitStruct.PLL.PLLR = RCC_PLLR_DIV2;
  if (HAL_RCC_OscConfig(&RCC_OscInitStruct) != HAL_OK) {
    mbed_die();
  }

  RCC_ClkInitStruct.ClockType      = (RCC_CLOCKTYPE_SYSCLK | RCC_CLOCKTYPE_HCLK | RCC_CLOCKTYPE_PCLK1 | RCC_CLOCKTYPE_PCLK2);
  RCC_ClkInitStruct.SYSCLKSource = RCC_SYSCLKSOURCE_PLLCLK;
  RCC_ClkInitStruct.AHBCLKDivider = RCC_SYSCLK_DIV1;
  RCC_ClkInitStruct.APB1CLKDivider = RCC_HCLK_DIV2;
  RCC_ClkInitStruct.APB2CLKDivider = RCC_HCLK_DIV2;

  if (HAL_RCC_ClockConfig(&RCC_ClkInitStruct, FLASH_LATENCY_6) != HAL_OK) {
    mbed_die();
  }

  {
    RCC_PeriphCLKInitTypeDef PeriphClkInit = {};

    PeriphClkInit.PeriphClockSelection = RCC_PERIPHCLK_FDCAN;
    PeriphClkInit.FdcanClockSelection = RCC_FDCANCLKSOURCE_PCLK1;
    if (HAL_RCCEx_PeriphCLKConfig(&PeriphClkInit) != HAL_OK)
    {
      mbed_die();
    }
  }
}

class ClockManager {
 public:
  ClockManager(fw::MillisecondTimer* timer,
               micro::PersistentConfig& persistent_config,
               micro::CommandManager& command_manager)
      : timer_(timer) {
    persistent_config.Register("clock", &clock_, [this]() {
        this->UpdateConfig();
      });
    command_manager.Register("clock", [this](auto&& command, auto&& response) {
        this->Command(command, response);
      });
  }

  int32_t clock_hz() const {
    return clock_.can_hz;
  }

  void UpdateConfig() {
    const int can_clock_hz = [&]() {
      if (clock_.can_hz >= 85000000) { return 85000000; }
      if (clock_.can_hz >= 80000000) { return 80000000; }
      if (clock_.can_hz >= 60000000) { return 60000000; }
      return 85000000;
    }();

    SetupClock(can_clock_hz * 2);

    const int32_t trim = std::max<int32_t>(0, std::min<int32_t>(127, clock_.hsitrim));
    RCC->ICSCR = (RCC->ICSCR & ~0xff000000) | (trim << 24);
  }

  void Command(const std::string_view& command,
               const micro::CommandManager::Response& response) {
    if (command == "us") {
      snprintf(output_, sizeof(output_), "%" PRIu32 "\r\n", timer_->read_us());
      WriteMessage(output_, response);
    } else {
      WriteMessage("ERR unknown clock\r\n", response);
    }
  }

  void WriteMessage(const std::string_view& message,
                    const micro::CommandManager::Response& response) {
    micro::AsyncWrite(*response.stream, message, response.callback);
  }

 private:
  struct Config {
    int32_t can_hz = 85000000;
    int32_t hsitrim = 64;

    template <typename Archive>
    void Serialize(Archive* a) {
      a->Visit(MJ_NVP(can_hz));
      a->Visit(MJ_NVP(hsitrim));
    }
  };

  fw::MillisecondTimer* const timer_;
  Config clock_;
  char output_[16] = {};
};
}

int main(void) {
  SetupClock(170000000);

  DigitalOut power_led{PB_5, 1};

  fw::MillisecondTimer timer;

  micro::SizedPool<20480> pool;

  fw::Stm32G4AsyncUsbCdc usb(
      &pool,
      [&]() {
        fw::Stm32G4AsyncUsbCdc::Options options;
        options.timer = &timer;
        return options;
      }());

  micro::AsyncExclusive<micro::AsyncWriteStream> write_stream(&usb);
  micro::CommandManager command_manager(
      &pool, &usb, &write_stream,
      []() {
        micro::CommandManager::Options options;
        options.max_line_length = 300;
        return options;
      }());

  char micro_output_buffer[2048] = {};
  micro::TelemetryManager telemetry_manager(
      &pool, &command_manager, &write_stream, micro_output_buffer);

  fw::Stm32G4Flash flash_interface;
  micro::PersistentConfig persistent_config(
      pool, command_manager, flash_interface, micro_output_buffer);

  fw::Uuid uuid(persistent_config);
  ClockManager clock(&timer, persistent_config, command_manager);

  fw::CanManager can_manager(
      pool, persistent_config, command_manager, write_stream,
      [&]() {
        fw::CanManager::Options options;
        options.td = PB_13;
        options.rd = PB_12;
        options.cdc = &usb;
        return options;
      }());

  fw::Stm32G4GsUsb gs_usb(pool, can_manager, [&]() {
    fw::Stm32G4GsUsb::Options options;
    options.get_can_clock_hz = [&]() { return clock.clock_hz(); };
    options.power_led = &power_led;
    options.timer = &timer;
    return options;
  }());

  usb.RegisterGsUsbHandler([&gs_usb](auto* dev, auto* req, auto* callback) {
    return gs_usb.HandleControl(dev, req, callback);
  });
  usb.RegisterGsUsbEndpointHandlers(
      [&gs_usb](usbd_device* dev, uint8_t event, uint8_t ep) {
        gs_usb.HandleRxEndpoint(dev, event, ep);
      },
      [&gs_usb](usbd_device* dev, uint8_t event, uint8_t ep) {
        gs_usb.HandleTxEndpoint(dev, event, ep);
      });
  can_manager.RegisterFrameCallback(
      [&gs_usb](const fw::CanManager::CanFrame& frame) {
        gs_usb.OnCanFrameReceived(frame);
      });

  fw::FirmwareInfo firmware_info(pool, telemetry_manager);

  fw::GitInfo git_info;
  telemetry_manager.Register("git", &git_info);

  persistent_config.Load();

  command_manager.AsyncStart();
  can_manager.Start();

#ifdef MJBOTS_XPRINTF_DEBUG
  fw::debug_print_init();
#endif

  auto old_time_ms = timer.read_ms();
  int tenms_count = 0;
  uint32_t loop_count = 0;

  while (true) {
    loop_count++;
#ifdef MJBOTS_XPRINTF_DEBUG
    fw::debug_print_poll();
#endif
    can_manager.Poll();
    usb.Poll();
    gs_usb.Poll();

    const auto new_time = timer.read_ms();
    if (new_time != old_time_ms) {
      old_time_ms = new_time;

      can_manager.PollMillisecond();
      gs_usb.PollMillisecond();

      tenms_count++;
      if (tenms_count >= 10) {
        can_manager.Poll10Ms();
        usb.Poll10Ms();

#ifndef MJBOTS_XPRINTF_DEBUG
        // To verify xprintf works:
        xprintf("loop_count %d\r\n", loop_count);
#endif

        tenms_count = 0;

      }
    }
  }
}

extern "C" {
void SysTick_Handler(void) {
  HAL_IncTick();
}

void abort() {
  mbed_die();
}
}

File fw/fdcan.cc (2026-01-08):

// Copyright 2019-2020 Josh Pieper, jjp@pobox.com.
//
// Licensed under the Apache License, Version 2.0 (the "License");
// you may not use this file except in compliance with the License.
// You may obtain a copy of the License at
//
//     http://www.apache.org/licenses/LICENSE-2.0
//
// Unless required by applicable law or agreed to in writing, software
// distributed under the License is distributed on an "AS IS" BASIS,
// WITHOUT WARRANTIES OR CONDITIONS OF ANY KIND, either express or implied.
// See the License for the specific language governing permissions and
// limitations under the License.

#include "fw/fdcan.h"

#include "PeripheralPins.h"

extern const PinMap PinMap_CAN_TD[];
extern const PinMap PinMap_CAN_RD[];

namespace fw {
namespace {
constexpr uint32_t RoundUpDlc(size_t size) {
  if (size == 0) { return FDCAN_DLC_BYTES_0; }
  if (size == 1) { return FDCAN_DLC_BYTES_1; }
  if (size == 2) { return FDCAN_DLC_BYTES_2; }
  if (size == 3) { return FDCAN_DLC_BYTES_3; }
  if (size == 4) { return FDCAN_DLC_BYTES_4; }
  if (size == 5) { return FDCAN_DLC_BYTES_5; }
  if (size == 6) { return FDCAN_DLC_BYTES_6; }
  if (size == 7) { return FDCAN_DLC_BYTES_7; }
  if (size == 8) { return FDCAN_DLC_BYTES_8; }
  if (size <= 12) { return FDCAN_DLC_BYTES_12; }
  if (size <= 16) { return FDCAN_DLC_BYTES_16; }
  if (size <= 20) { return FDCAN_DLC_BYTES_20; }
  if (size <= 24) { return FDCAN_DLC_BYTES_24; }
  if (size <= 32) { return FDCAN_DLC_BYTES_32; }
  if (size <= 48) { return FDCAN_DLC_BYTES_48; }
  if (size <= 64) { return FDCAN_DLC_BYTES_64; }
  return 0;
}

FDCan::Rate MakeTime(int bitrate, int max_time_seg1, int max_time_seg2,
                     float sample_point) {
  FDCan::Rate result;

  result.prescaler = 1;

  uint32_t pclk1 = HAL_RCC_GetPCLK1Freq();
  uint32_t total_divisor = 0;

  while (true) {
    total_divisor = (pclk1 / result.prescaler) / bitrate;

    // One of the divisor counts comes for free.
    const auto actual_divisor = total_divisor - 1;

    // Split up the remainder to get the desired sample point.
    result.time_seg2 = static_cast<int>(
        static_cast<float>(actual_divisor) * (1.0f - sample_point));
    result.time_seg1 = actual_divisor - result.time_seg2;

    result.sync_jump_width = std::min(16, result.time_seg2);

    if (result.time_seg1 > max_time_seg1 ||
        result.time_seg2 > max_time_seg2) {
      result.prescaler++;
      continue;
    }

    break;
  }

  return result;
}

FDCan::Rate ApplyRateOverride(FDCan::Rate base, FDCan::Rate overlay) {
  if (overlay.prescaler >= 0) {
    base.prescaler = overlay.prescaler;
  }
  if (overlay.sync_jump_width >= 0) {
    base.sync_jump_width = overlay.sync_jump_width;
  }
  if (overlay.time_seg1 >= 0) {
    base.time_seg1 = overlay.time_seg1;
  }
  if (overlay.time_seg2 >= 0) {
    base.time_seg2 = overlay.time_seg2;
  }
  return base;
}
}

FDCan::FDCan(const Options& options)
    : options_(options) {
  __HAL_RCC_FDCAN_CLK_ENABLE();

  {
    const auto can_td = pinmap_peripheral(options.td, PinMap_CAN_TD);
    const auto can_rd = pinmap_peripheral(options.rd, PinMap_CAN_RD);
    can_ = reinterpret_cast<FDCAN_GlobalTypeDef*>(
        pinmap_merge(can_td, can_rd));
  }

  pinmap_pinout(options.td, PinMap_CAN_TD);
  pinmap_pinout(options.rd, PinMap_CAN_RD);

  auto& can = hfdcan1_;

  can.Instance = can_;
  can.Init.ClockDivider = FDCAN_CLOCK_DIV1;
  can.Init.FrameFormat = [&]() {
    if (options.fdcan_frame && options.bitrate_switch) {
      return FDCAN_FRAME_FD_BRS;
    } else if (options.fdcan_frame) {
      return FDCAN_FRAME_FD_NO_BRS;
    }
    return FDCAN_FRAME_CLASSIC;
  }();
  can.Init.Mode = [&]() {
    if (options.loopback) {
      return FDCAN_MODE_INTERNAL_LOOPBACK;
    } else if (options.bus_monitor) {
      return FDCAN_MODE_BUS_MONITORING;
    } else if (options.restricted_mode) {
      return FDCAN_MODE_RESTRICTED_OPERATION;
    }
    return FDCAN_MODE_NORMAL;
  }();
  can.Init.AutoRetransmission =
      options.automatic_retransmission ? ENABLE : DISABLE;
  can.Init.TransmitPause = ENABLE;
  can.Init.ProtocolException = DISABLE;

  auto nominal = ApplyRateOverride(
      MakeTime(options.slow_bitrate, 255, 127, options.slow_sample_point),
      options.rate_override);
  auto fast = ApplyRateOverride(
      MakeTime(options.fast_bitrate, 31, 15, options.fast_sample_point),
      options.fdrate_override);

  config_.clock = HAL_RCC_GetPCLK1Freq();
  config_.nominal = nominal;
  config_.data = fast;

  can.Init.NominalPrescaler = nominal.prescaler;
  can.Init.NominalSyncJumpWidth = nominal.sync_jump_width;
  can.Init.NominalTimeSeg1 = nominal.time_seg1;
  can.Init.NominalTimeSeg2 = nominal.time_seg2;

  can.Init.DataPrescaler = fast.prescaler;
  can.Init.DataSyncJumpWidth = fast.sync_jump_width;
  can.Init.DataTimeSeg1 = fast.time_seg1;
  can.Init.DataTimeSeg2 = fast.time_seg2;

  can.Init.StdFiltersNbr =
      std::count_if(
          options.filter_begin, options.filter_end,
          [](const auto& filter) {
            return (filter.action != FilterAction::kDisable &&
                    filter.type == FilterType::kStandard);
          });
  can.Init.ExtFiltersNbr =
      std::count_if(
          options.filter_begin, options.filter_end,
          [](const auto& filter) {
            return (filter.action != FilterAction::kDisable &&
                    filter.type == FilterType::kExtended);
          });
  can.Init.TxFifoQueueMode = FDCAN_TX_FIFO_OPERATION;
  if (HAL_FDCAN_Init(&can) != HAL_OK) {
    mbed_die();
  }

  int standard_index = 0;
  int extended_index = 0;
  std::for_each(
      options.filter_begin, options.filter_end,
      [&](const auto& filter) {
        if (filter.action == FilterAction::kDisable) {
          return;
        }

        FDCAN_FilterTypeDef sFilterConfig;
        sFilterConfig.IdType = [&]() {
          switch (filter.type) {
            case FilterType::kStandard: return FDCAN_STANDARD_ID;
            case FilterType::kExtended: return FDCAN_EXTENDED_ID;
          }
          mbed_die();
        }();
        sFilterConfig.FilterIndex = [&]() {
          switch (filter.type) {
            case FilterType::kStandard: {
              return standard_index++;
            }
            case FilterType::kExtended: {
              return extended_index++;
            }
          }
          mbed_die();
        }();
        sFilterConfig.FilterType = [&]() {
          switch (filter.mode) {
            case FilterMode::kRange: return FDCAN_FILTER_RANGE;
            case FilterMode::kDual: return FDCAN_FILTER_DUAL;
            case FilterMode::kMask: return FDCAN_FILTER_MASK;
          }
          mbed_die();
        }();
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

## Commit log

2019-10-07 Initial version of fdcanusb
    [fdcanusb.brd, fdcanusb.sch]
2019-10-07 Finish BOM and fine silk placement
    [fdcanusb.brd, fdcanusb.sch]
2019-10-07 More BOM tweaks
    [fdcanusb.brd, fdcanusb.sch]
2019-10-07 Mark pin 1 on optocoupler
    [fdcanusb.brd, fdcanusb.sch]
2019-10-07 Switch to actually using a micro USB connector
    [fdcanusb.brd, fdcanusb.sch]
2019-11-18 Update to use correct STM32 pinout
    [fdcanusb.brd, fdcanusb.sch]
2019-11-18 Record the r1 version
    [fdcanusb.brd, fdcanusb.sch]
2019-11-18 Use the digikey number for DB9, since MF can find it
    [fdcanusb.brd, fdcanusb.sch]
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2019-12-03 Switch to using Stm32Serial after fixing it to use proper #defines
    [stm32_serial.cc, stm32g4_async_uart.cc]
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2019-12-08 Update the maximum line length to 300
    This is useful, since sending a 64 byte can frame takes at least 128
    bytes plus the start and end of the command and optional flags.
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2019-12-11 Use the correct CAN peripheral for the pins selected
    [fdcan.cc]
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2019-12-11 r2 of fdcanusb board
    [fdcanusb.brd, fdcanusb.sch]
2019-12-11 Fix DB9 pinout
    [fdcanusb.brd, fdcanusb.sch]
2019-12-12 Properly read data when a single CDC frame gives us more than 1 byte
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2020-01-23 Capture r2.1
    [fdcanusb.brd, fdcanusb.sch]
2020-01-24 Update to r2.2
    This just reduces the size of the PCB so it doesn't hang out so far
    under the DB-9 connector.
    [fdcanusb.brd, fdcanusb.sch]
2020-01-24 Draft enclosure
    [fdcanusb_enclosure.3mf, fdcanusb_enclosure_bottom.stl, fdcanusb_enclosure_top.stl]
2020-01-27 Switch LED resistors back to 220s
    [fdcanusb.brd, fdcanusb.sch]
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2020-02-28 Provide more bitrate options
    This provides knobs to make the device more interoperable with other
    CAN devices.
2020-10-22 A minimal tool to bridge fdcanusb and socketcan
    This has worked in one basic test, but hasn't received much testing
    otherwise. It bridges a virtual CAN interface and the fdcanusb.
2020-12-10 If we can't write yet, don't bother pulling off a packet
    This logic previously could cause the fdcanusb to "drop" packets, if
    one came in while it was in the middle of sending something to the USB
    bus. Now it will at least use the FDCAN peripheral's buffers to hold
    the frames until the USB write is complete. Overruns are still
    possible, but at least our buffer size is non-zero.
2021-01-17 Capture r2.2
    [fdcanusb.brd, fdcanusb.sch]
2021-01-17 Make DB9 have plated holes for retaining clips
    This should improve the mechanical strength of the DB9 connector when
    installed
    [fdcanusb.brd, fdcanusb.sch]
2021-01-18 Tweak silk position
    [fdcanusb.brd]
2021-01-18 r2.3 as sent for mf
    [fdcanusb.brd, fdcanusb.sch]
2022-01-15 fdcanusb_daemon: Work with serial port in raw mode
    If the daemon was the only thing that opened the serial port, it would
    not be in raw mode. The kernel would echo some of the characters the
    device sent back to it, which confused things greatly.
2022-11-02 Update PCB to fdcanusb r2.4 * All components are increased to minimum 0603 * Switch to the SOIC package for the CAN transceiver, which is easier to get * Switch to 6mil min space/trace
    [fdcanusb.brd, fdcanusb.sch]
2022-11-02 Fix some housepart designations
    [fdcanusb.brd, fdcanusb.sch]
2022-11-02 Fine silk placement
    [fdcanusb.brd, fdcanusb.sch]
2022-11-02 More fine silk and slight routing
    [fdcanusb.brd]
2022-11-02 Fix resistor footprint
    [fdcanusb.brd, fdcanusb.sch]
2022-11-02 r3.0 as sent to oshpark
    [fdcanusb.brd, fdcanusb.sch]
2022-11-02 SCHEMATIC ONLY work on more CAN transceiver variants
    Update schematic, but not PCB, to accept the TCAN1057AEV in addition
    to the 3.3V native variants.
    [fdcanusb.brd, fdcanusb.sch]
2022-11-02 Nominally complete fdcanusb w/ support for all known SOIC8/SOT8 CAN
    * This will work with all the 3.3V and 5V 8 pin parts I know of with
    no more than different resistor populations.
    [fdcanusb.brd, fdcanusb.sch]
2022-11-02 More silk tweaks
    [fdcanusb.brd, fdcanusb.sch]
2022-11-03 Add a decoupling cap on VIO
    [fdcanusb.brd, fdcanusb.sch]
2022-11-03 r2.5 as sent to oshpark
    [fdcanusb.brd, fdcanusb.sch]
2022-11-21 Add support for delay compensation and enable it by default
    This is required to operate on boards with the TCAN1057, but still
    works on older fdcanusbs as well.
2023-09-19 Remove the never-produced r3
    [fdcanusb.brd, fdcanusb.sch]
2024-03-06 WIP of a KiCad fdcanusb r4
    [B6B-ZR-SM4-TF.STEP, S3B-PH-SM4-TB_LF__SN_.step, UFQFPN-48_7X7X0P55MM.step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]
2024-03-06 WIP - nearly all routing complete
    [can.kicad_sch, fdcanusb.kicad_pcb, fdcanusb.kicad_sch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]
2024-03-06 Maybe complete routing and passes all DRC
    [fdcanusb.kicad_pcb]
2024-03-06 r4: Add board label and fine silk tune
    [fdcanusb.kicad_pcb]
2024-03-06 r4: More work to get silk off vias
    [fdcanusb.kicad_pcb]
2024-03-06 Add debug pads for power rails
    [fdcanusb.kicad_pcb, led_debug.kicad_sch]
2024-03-06 Re-run DRC and zone fill, set layers
    [fdcanusb.kicad_pcb]
2024-03-06 Set up kicadbom and make a pass at filling in all bom entries
    [power_input.kicad_sch, stm32g4.kicad_sch]
2024-03-06 r4.1: Swith to an actual SMT USB-C connector
    [fdcanusb.kicad_pcb, power_input.kicad_sch, usb4110-gf-a.stp]
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2024-03-06 r4.1 as mfg
    [can.kicad_sch, fdcanusb.kicad_pcb, fdcanusb.kicad_sch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]
2024-03-06 Add title block and update rev to r4.2
    [can.kicad_sch, fdcanusb.kicad_pcb, fdcanusb.kicad_sch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]
2025-01-06 Support both classic and FD CAN frames in daemon
    By adding this functionality, the fdcanusb can be used as a general-purpose CAN adapter with a bunch of existing tools, correctly preserving the frame type, as well as RTR and BRS flags.
2025-01-06 fdcanusb_daemon: Switch to using blocking I/O
    Previously, the program would error if the fdcanusb adapter was busy, due to EAGAIN return value from the write call.
    This would occationally happen during periods with messages in rapid succession.
    By switching to blocking IO, the program will instead wait for the device to become ready.
2025-01-14 Implement `can.autorecover`
    This can be used to make communication more reliable if your CAN-FD
    bus has electrical problems.
    [fdcan.cc, fdcan.h]
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2025-09-12 Add buffers and optimize performance
    When receiving frames, we now have at a minimum a 2k buffer of
    formatted ASCII output, which will in practice provide for at least 8
    frames and possibly many more.
    We were spending *a lot* of time formatting the string responses. Fix
    that by stopping usage of sprintf.
2025-09-13 Switch to a more useful flashing script that can take an arbitrary .elf
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2025-09-19 Switch the fdcanusb to use auto-retransmit by default
    This will make it able to reliably address more than 2 or 3 devices.
    To get around the problems caused by sending never-acknowledged
    frames, we cancel all frames in the hw queue after by default 50ms
    after the last frame was entered into the hw queue.
    [fdcan.cc, fdcan.h, fdcanusb.cc]
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2026-01-08 Add an integration test covering buffer backups
    Ensure that if either of the two interfaces is never opened, it
    doesn't interfere with receiving large number of frames on the other
    interface.
    [fdcanusb_test_utils.py, test_hardware_in_loop.py]
2026-01-08 gs_usb: Implement one-shot mode
    This was tested manually on the fixture with the legacy device in bus monitor mode and using:
    `ip link set can0 up type can one-shot on`
2026-01-08 gs_usb: Implement loopback and error count reporting
    Loopback was tested by using `loopback on` or `loopback off` on the
    test fixture.
    Error reporting was tested by using `ip -details link show can0`. For
    tx errors, the other device was set in bus monitor mode, which maxed
    out errors, then when disabled, errors decrease by one per frame sent.
    For rx errors, the other device was set with a CAN 2.0 sample point of
    0.8 and a frame sent which maxed out the errors. Setting it back to
    0.666 decreased the rx errors one per frame received.
    [fdcan.cc, fdcan.h]
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2026-10-06 gs_usb: Always send full length USB frames
    Older linux kernels and Windows would happily accept shorter than
    maximum length USB frames. As of a revent CVE fix, Linux no longer
    does so. Thus fill everything out to the maximum for that frame type.
    While we are at it, correctly place the timestamp at the right place
    in the structure.

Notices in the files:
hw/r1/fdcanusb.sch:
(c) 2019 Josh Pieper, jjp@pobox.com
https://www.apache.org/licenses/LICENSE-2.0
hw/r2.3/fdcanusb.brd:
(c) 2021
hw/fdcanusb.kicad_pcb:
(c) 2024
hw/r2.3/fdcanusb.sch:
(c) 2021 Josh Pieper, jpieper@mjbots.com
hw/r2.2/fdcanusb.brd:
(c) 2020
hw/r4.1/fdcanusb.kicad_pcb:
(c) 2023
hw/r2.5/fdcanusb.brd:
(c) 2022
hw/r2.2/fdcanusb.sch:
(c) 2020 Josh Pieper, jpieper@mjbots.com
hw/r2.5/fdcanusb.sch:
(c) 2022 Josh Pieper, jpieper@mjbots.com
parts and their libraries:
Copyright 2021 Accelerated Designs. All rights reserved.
